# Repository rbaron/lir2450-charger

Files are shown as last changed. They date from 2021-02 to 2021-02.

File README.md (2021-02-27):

# LIR2450 Charger

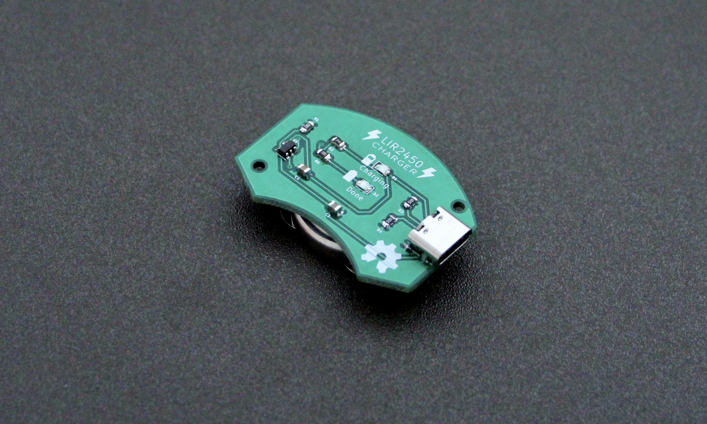
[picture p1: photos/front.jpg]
Front

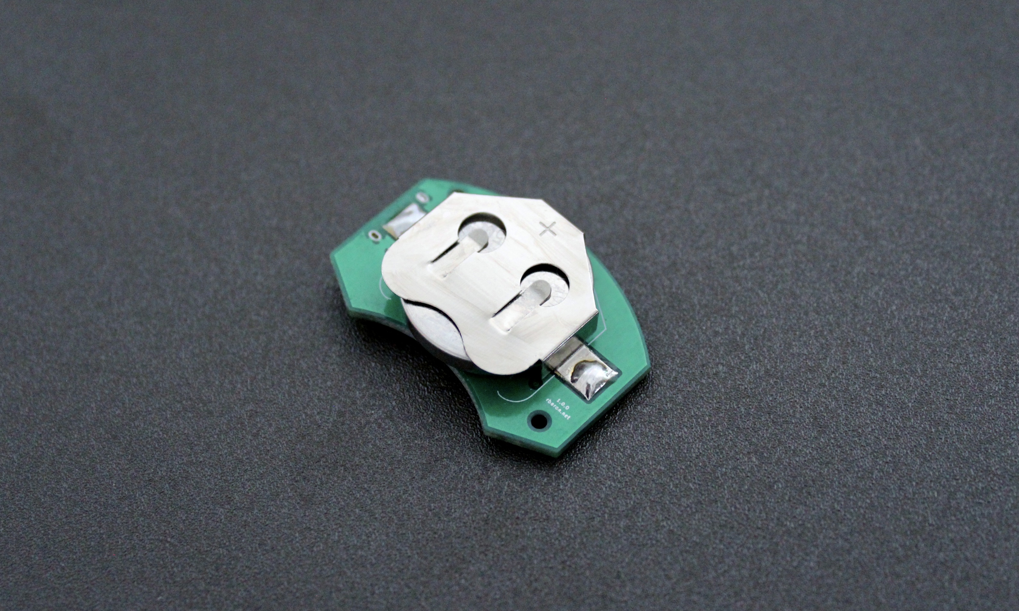
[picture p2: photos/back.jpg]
Back

An open source USB C battery charger for [LIR2450 Li-Ion coin cells](https://www.adafruit.com/product/1572).

This repo hosts the [KiCad](https://kicad.org/) project for the charger, which contains the schematic and printed circuit board layout so you can make your own.

# Tech Specs
* It uses Microchip's [MCP73831](https://www.microchip.com/wwwproducts/en/en024903) as the charge management controller
* 45mA charge current

# Bill of Materials (BOM)
The KiCad exported BOM is [here](kicad/lir2450-charger.csv).

# 3D Render
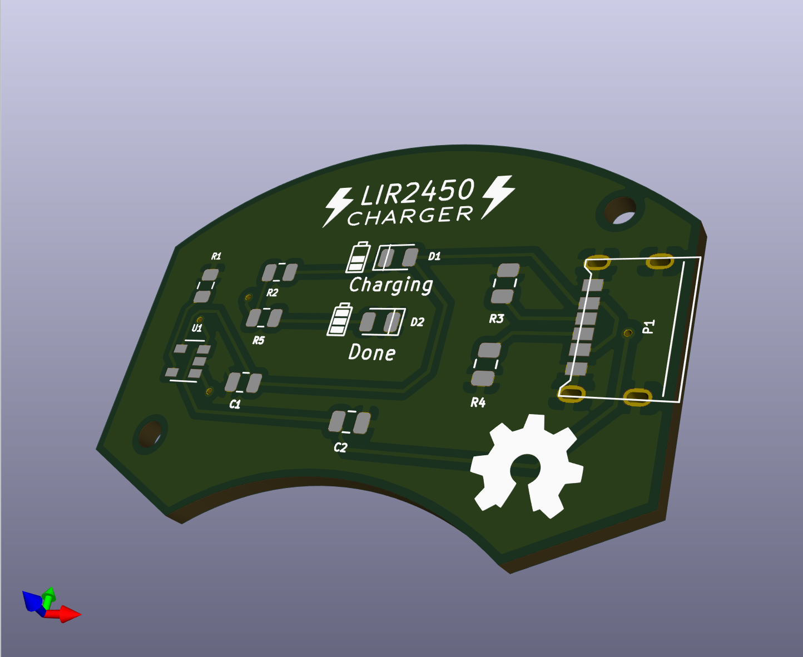
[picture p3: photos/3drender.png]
3D Render


# License
The hardware and associated design files are released under the [Creative Commons CC BY-SA 4.0 license](https://creativecommons.org/licenses/by-sa/4.0/).

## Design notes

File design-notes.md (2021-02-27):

These are some loose notes I took during the project.

# USB-C connector
I have a "cheap" USB-C connector (very similart to [this one](https://www.cuidevices.com/product/resource/ujc-hp-3-smt-tr.pdf)) that has only 6 pins. It is power only and should be solderable by hand.

No footprints in kicad for this cheap USB-C model that has only 6 pins. I found these footprints on [GitHub](https://github.com/jenschr/USB-C-Connectors/tree/master/Kicad/Footprints). One of them (TYPE-C-31-M-17) seem to match the connector I have.

## USB-C LiPo charger from SparkFun
 - [Datasheet](https://www.distrelec.ch/Web/Downloads/_t/ds/PRT-15217_eng_tds.pdf)
 - The two VBUS pins are shorted together. So are grounds.

## USB-C Power
Useful info from this [StackOverflow thread](https://electronics.stackexchange.com/a/327946):
- CC pins should both be pulled down by a 5.1k resistor.

# LIR2450
- 120-ish mAh capacity
- 45mA charging current

## Battery charger IC
- [MCP73831](https://www.sparkfun.com/datasheets/Prototyping/Batteries/MCP73831T.pdf)
- The charging current is programmable via the R_prog resistor:
    I_reg = 1000 V / R_prog
    => For a 45mA ccurrent:
    R_prog = 1000 / 45e-3 = 22.2k

Nice! This value (22k) is the exact same one as used in [this charger](https://www.theledart.com/collections/usb-powered/products/lir2450-battery-charger). I could probably use 2 * 47k in parallel, since I have these already (although I might need to get 5.1k anyway...).

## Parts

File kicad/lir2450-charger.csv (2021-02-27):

Id | Designator | Package | Quantity | Designation | Supplier and ref
1 | REF** | OSHW-Symbol_6.7x6mm_SilkScreen | 1 | OSHW-Symbol_6.7x6mm_SilkScreen
2 | G*** | battery-full | 1 | LOGO
3 | G*** | battery-half | 1 | LOGO
4 | G***,G*** | spark | 2 | LOGO
5 | BAT1 | BatteryHolder_Keystone_3008_1x2450 | 1 | BS-7
6 | R5,R2 | R_0805_2012Metric | 2 | 220
7 | D2 | LED_0805_2012Metric | 1 | Green LED
8 | P1 | TYPE-C-31-M-17 | 1 | USB_C_Plug_USB2.0
9 | U1 | SOT-23-5 | 1 | MCP73831-2-OT
10 | R4,R3 | R_0805_2012Metric | 2 | 5.1k
11 | R1 | R_0805_2012Metric | 1 | 22k
12 | D1 | LED_0805_2012Metric | 1 | Red LED
13 | C2,C1 | C_0805_2012Metric | 2 | 4.7u

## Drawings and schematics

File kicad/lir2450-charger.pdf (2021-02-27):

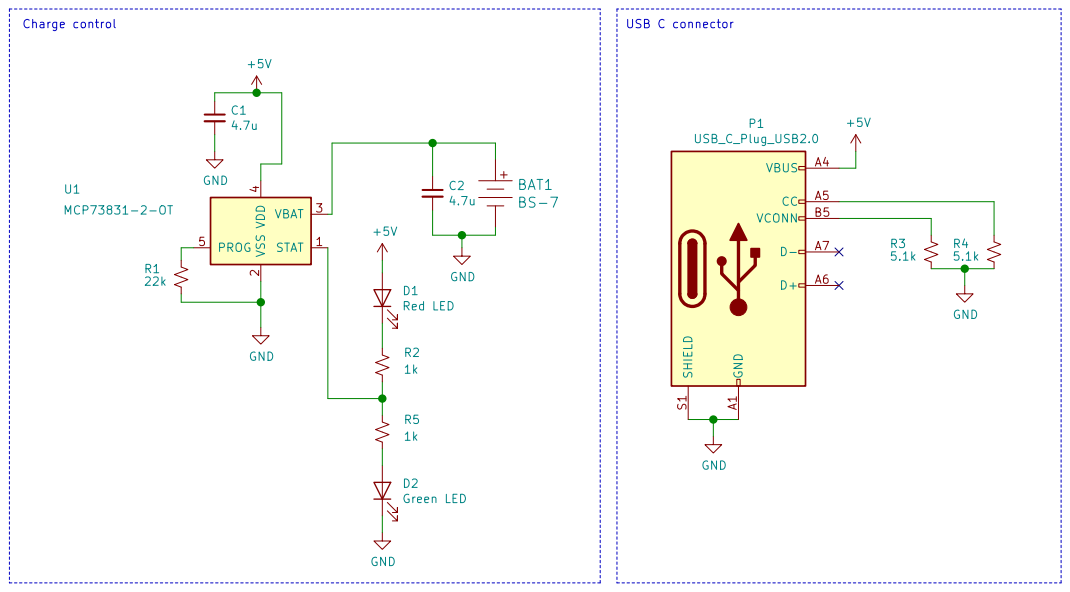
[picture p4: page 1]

File: lir2450-charger.sch Sheet: / rbaron.net

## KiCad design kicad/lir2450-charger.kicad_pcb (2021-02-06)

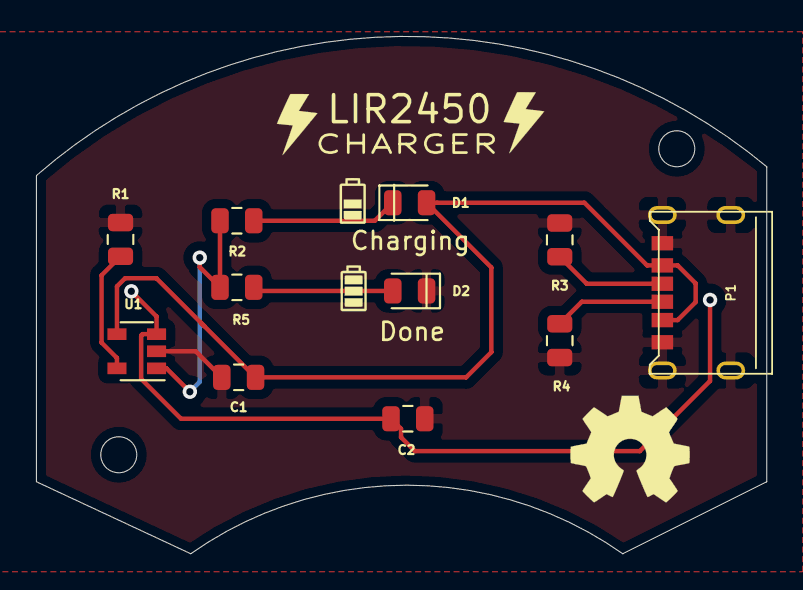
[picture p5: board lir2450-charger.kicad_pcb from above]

Board: 2 copper layers, 40.6 x 28.7 mm, 12 parts (1 on the bottom side), 9 nets.

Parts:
BAT1: BS-7; BatteryHolder_Keystone_3008_1x2450
C1, C2: 4.7u; C_0805_2012Metric
D1: Red LED; LED_0805_2012Metric
D2: Green LED; LED_0805_2012Metric
P1: USB_C_Plug_USB2.0; TYPE-C-31-M-17
R1: 22k; R_0805_2012Metric
R2, R5: 220; R_0805_2012Metric
R3, R4: 5.1k; R_0805_2012Metric
U1: MCP73831-2-OT; SOT-23-5

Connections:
+5V: C1.1, D1.2, P1.A9, P1.B9, U1.4
GND: BAT1.Neg, C1.2, C2.2, D2.1, P1.A12, P1.B12, P1.S1, R1.2, R3.2, R4.2, U1.2
unnamed: BAT1.Pos, C2.1, U1.3
unnamed: D1.1, R2.1
unnamed: D2.2, R5.2
unnamed: P1.A5, R4.1
unnamed: P1.B5, R3.1
unnamed: R1.1, U1.5
unnamed: R2.2, R5.1, U1.1

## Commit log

2021-01-26 Adds green led & pcb icons
    [lir2450-charger.kicad_pcb, lir2450-charger.sch]
2021-02-05 Correct battery clip polarity
    [lir2450-charger.kicad_pcb]
2021-02-06 Re-routes some tracks to avoid vias too close to the battery negative pad
    [lir2450-charger-B_Cu.gbr, lir2450-charger-B_Mask.gbr, lir2450-charger-B_Paste.gbr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]
2021-02-06 Adds proper battery footprint
    [lir2450-charger-B_Cu.gbr, lir2450-charger-B_Mask.gbr, lir2450-charger-B_Paste.gbr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]
2021-02-06 Plotted v1.0.0
    [lir2450-charger.kicad_pcb]
2021-02-27 Updates R2 and R5 to 1k
    [lir2450-charger.sch]
2021-02-27 Adds a README.md and LICENSE
    [lir2450-charger-B_Cu.gbr, lir2450-charger-B_Mask.gbr, lir2450-charger-B_Paste.gbr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]
2021-02-27 Adds bill of materials to README.md
